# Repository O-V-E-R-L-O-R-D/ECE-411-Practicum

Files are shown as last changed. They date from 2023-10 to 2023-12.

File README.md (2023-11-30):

# ECE-411-Practicum Project

## Color Sensor State Diagram


## Bootload and Programming
**Library for Bootload Raw Chip:** https://github.com/MCUdude/
MiniCore

**1.) Add "https://mcudude.github.io/MiniCore/package_MCUdude_MiniCore_index.json" to Arduino IDE's "Additional boards manager URL's"**

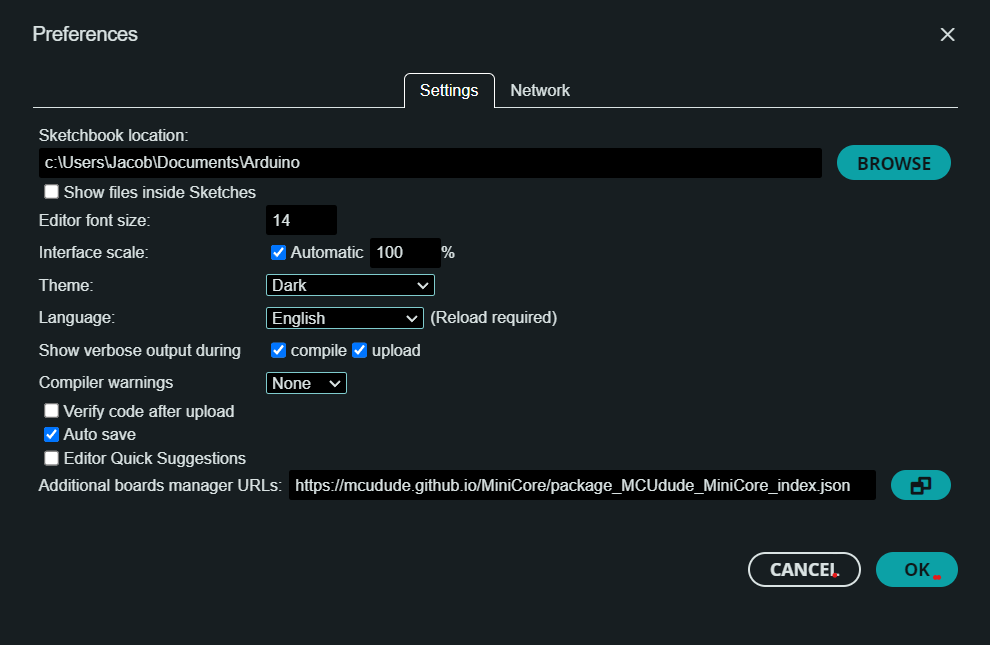
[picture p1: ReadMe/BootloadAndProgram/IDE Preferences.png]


---
**2.) Open example project "AruinoISP"**

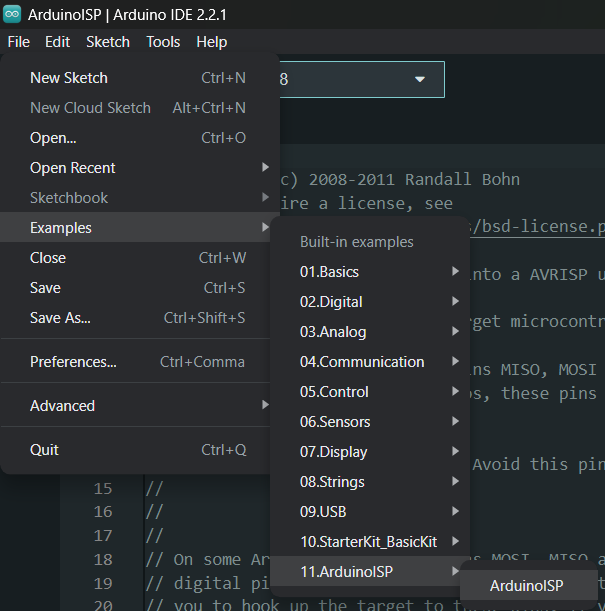
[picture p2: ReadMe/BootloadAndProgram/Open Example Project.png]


---
**3.) Program Arduino Uno for programming by clicking "Upload button" with the Aruino Uno board selected. Also in the "Tools" tab select "ArduinoISP" for programmer** 

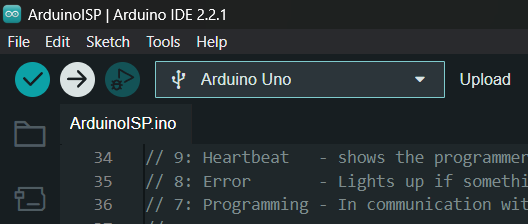
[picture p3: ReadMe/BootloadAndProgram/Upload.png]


---
**4.) Make connections from Aruduino Uno to PCB. On PCB, move bottem left switch to Program Mode (PRGM) by sliding the switch to the left**

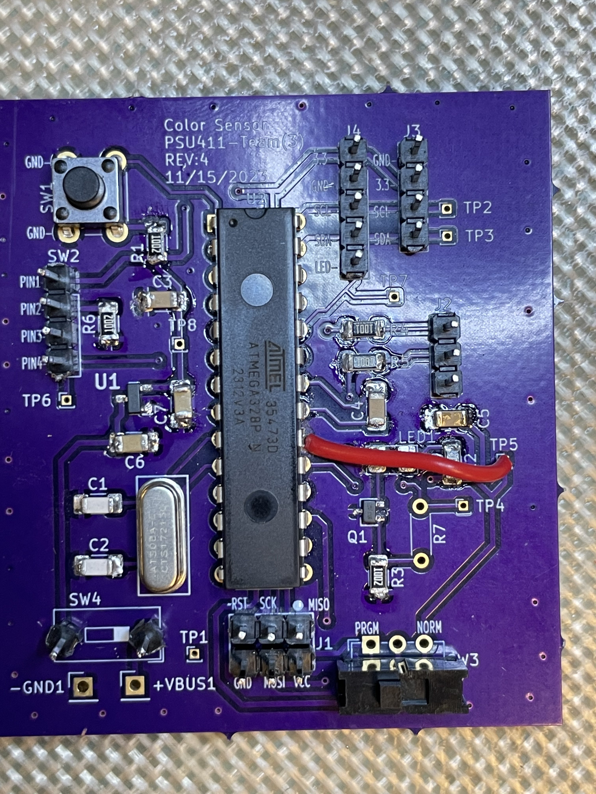
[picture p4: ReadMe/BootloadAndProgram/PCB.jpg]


| Arduino Uno |->| PCB |
|---|--|-----|
|5V |->|VCC  | 
|GND |->|GND  |
|13 |->|CLK  |
|12 |->|MISO |
|11 |->|MOSI |
|10 |->|Reset|

---
**5.) Bootload ATmega328 by opening "Tools tab and clicking "Burn Bootloader" after changing the settings to the ones seen below.**  
Board: "ATmega328"
BOD: 2.7V  
Clock: "External 8MHz"  
EEPROM: "EEPROM not retained"  (Not Necessary, For Clearing Color Calibration data)  
Variant: "328P/32PA"  
Programmer: "Arduino as ISP"  

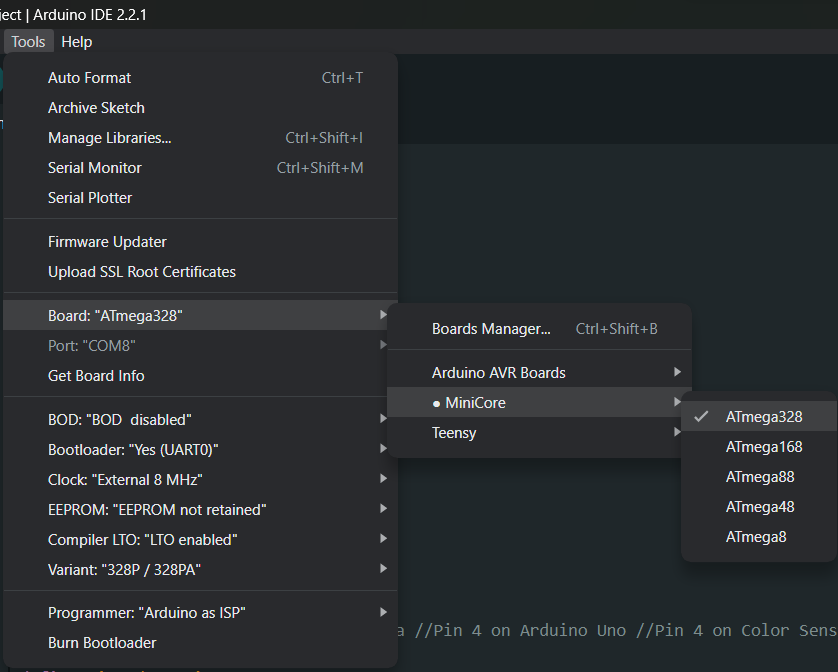
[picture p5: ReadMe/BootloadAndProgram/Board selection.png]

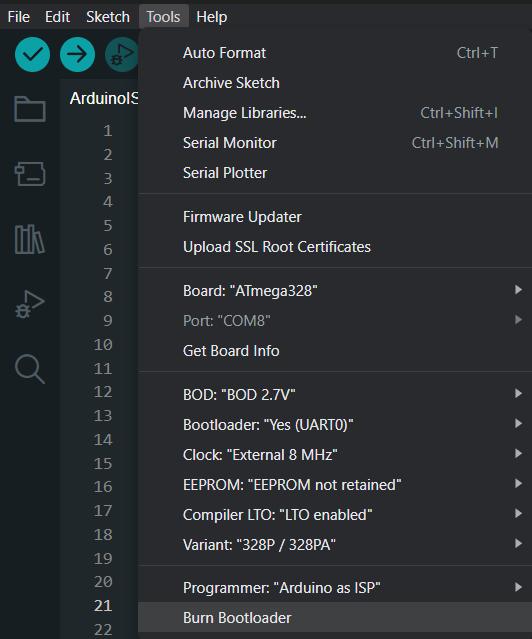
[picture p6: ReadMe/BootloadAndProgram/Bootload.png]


---
**6.) Switch to RGB_Sensor_Project.ino ("ECE-411-Practicum/RGB_sensor_project/RGB_sensor_project.ino"). Open Tools tab and make sure "Programmer" is set to "Arduino as ISP".With the ATmega328 board selected, open the "Sketch" tab and click "Upload Using Programmer"**

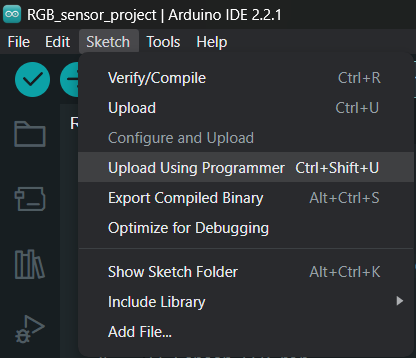
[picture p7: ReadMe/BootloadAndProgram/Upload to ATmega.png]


---
**7.) Unplug Programming connectings to PCB and flip the bottom right switch on the PCB to "NORM" mode. Make sure the PCB is getting power from the batter to the PCB. If this is the firt time programming the device the OLED should show that it's entering calibration mode.**  

**NOTE:** After first bootload you don't need to do it again for that chip. If you want to upload a new Schetch to the chip you only need to flip bottem left switch to PRGM, make the right programming connections, and then go straight to step 6.

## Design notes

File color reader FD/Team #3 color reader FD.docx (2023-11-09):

Team #3

Functional Decomposition

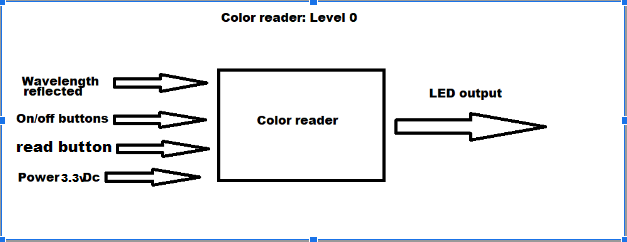
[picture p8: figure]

Module | Color reader
Inputs | Color: wavelength On/Off and read control: buttons Power: 3.3v Dc
Outputs | Led displaying the color
Functionality | Reads the reflected wavelength then converts and displays the color on the LCD. User should be able to turn it on/off and when to take the a new reading

Color reader: Level 1

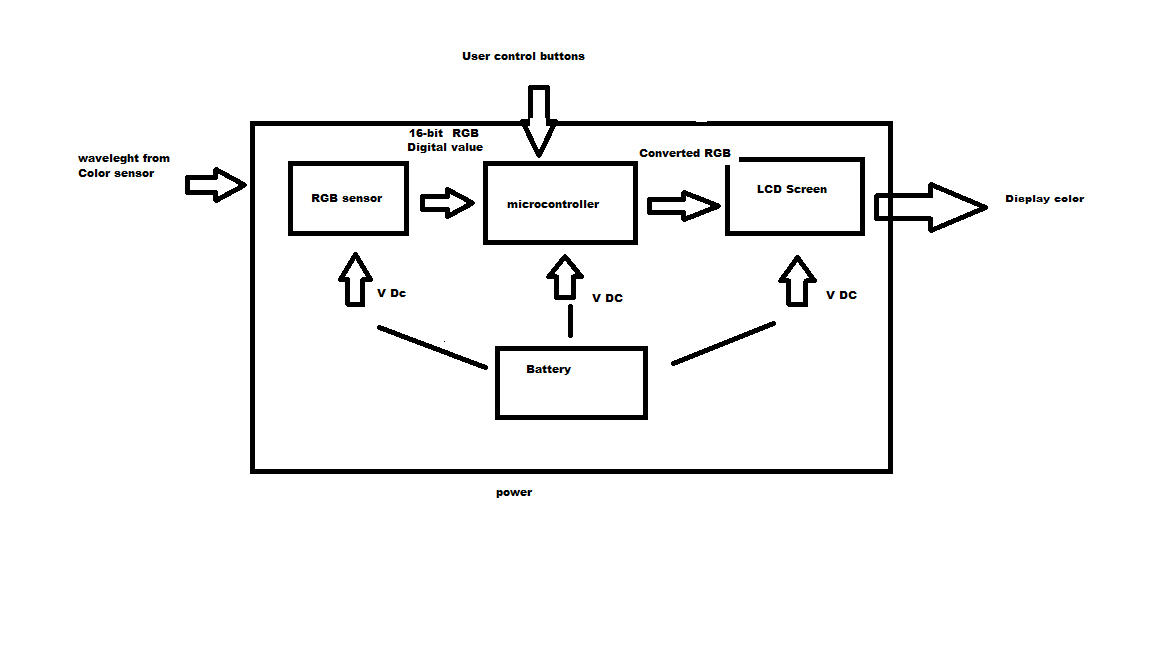
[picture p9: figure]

Module | RGB sensor
Inputs | Wavelength reflected Power: 0.5v to 3.8v
Outputs | RGB 16-bit Digital value
Functionality | Provides a digital value of RGB of incoming light

Module | Battery
Inputs | Power 9V
Outputs | 9V dc battery
Functionality | Provide power to turn on

Module | LCD screen
Inputs | Converted RGB digital Power: 5v
Outputs | Readable information
Functionality | Displays to the user the color

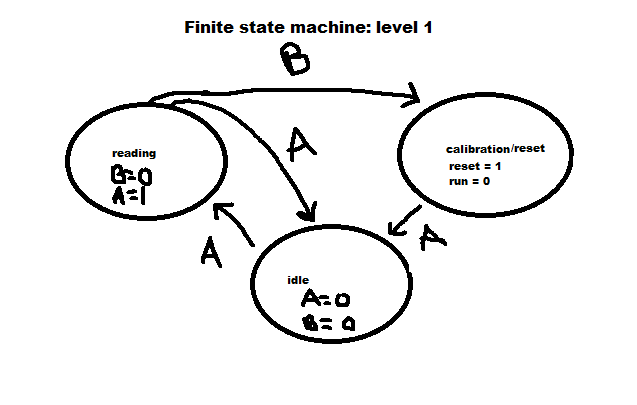
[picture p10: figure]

Module | microcontroller
Inputs | Power: 2.7v to 5.5v Clock: 0 to 8MHz Color sensor
Outputs | Reset/read modes LCD Color sensor
Functionality | Changes the color sensor from reset and run modes

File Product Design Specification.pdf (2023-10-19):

# HW Wk 04 - Product Design Specification ECE 411

# Team #3:

## Jacob Louie (jlouie@pdx.edu) Vladimir Grigoriev (vg8@pdx.edu) Kiryl Rabushka (rabushka@pdx.edu) Tristan Josue (jtristan@pdx.edu)

## Instructor: Andrew Greenberg

## ECE DEPARTMENT

PORTLAND STATE UNIVERSITY

Product summary:
Our product is a pen shaped color picker. By pointing the tip of the pen at an object, it can display the hex color code of that object. This hex code can then be replicated into your own digital art project by using that same hex code. This device can be especially helpful for people that are color-blind. Outside digital projects, it can also be used to match the paint color of an object in order to apply some new paint. This product is for anyone that might need some help restoring or bringing to life the colors of reality for your projects.

“Market” Analysis:
Targeted Customers: Digital artist, painters, interior designers, DIY projects, and color-blind people.

Competition: Other color analysis software/app, cheaper color readers, “eyeball test”

Price: 50$ this is our reference price based on the research of similar projects.

We may have to lower the price in the future baced on the components we use to make it much cheaper for the customers. Other color analysis devises on the internet are much more complex and cost a lot of money. We shoot for cheap smal device for everyday life and easy to use, so everyone can easily have hands on it and do not spent a lot of money.

Requirements:
- Must: Read color, output a hex code to display, be portable, run on battery.
- Should: Be small and light, have an LED or a buzzer to indicate the state of color identification process.
- May: Give out the complementary colors, ergonomic, rechargeable, have an app, have an RGB LED to display the color

System Architecture:
Those are the major parts we will be using in our product:
- Color Sensor
- Microcontroller
- Battery
- Voltage regulator
- Display

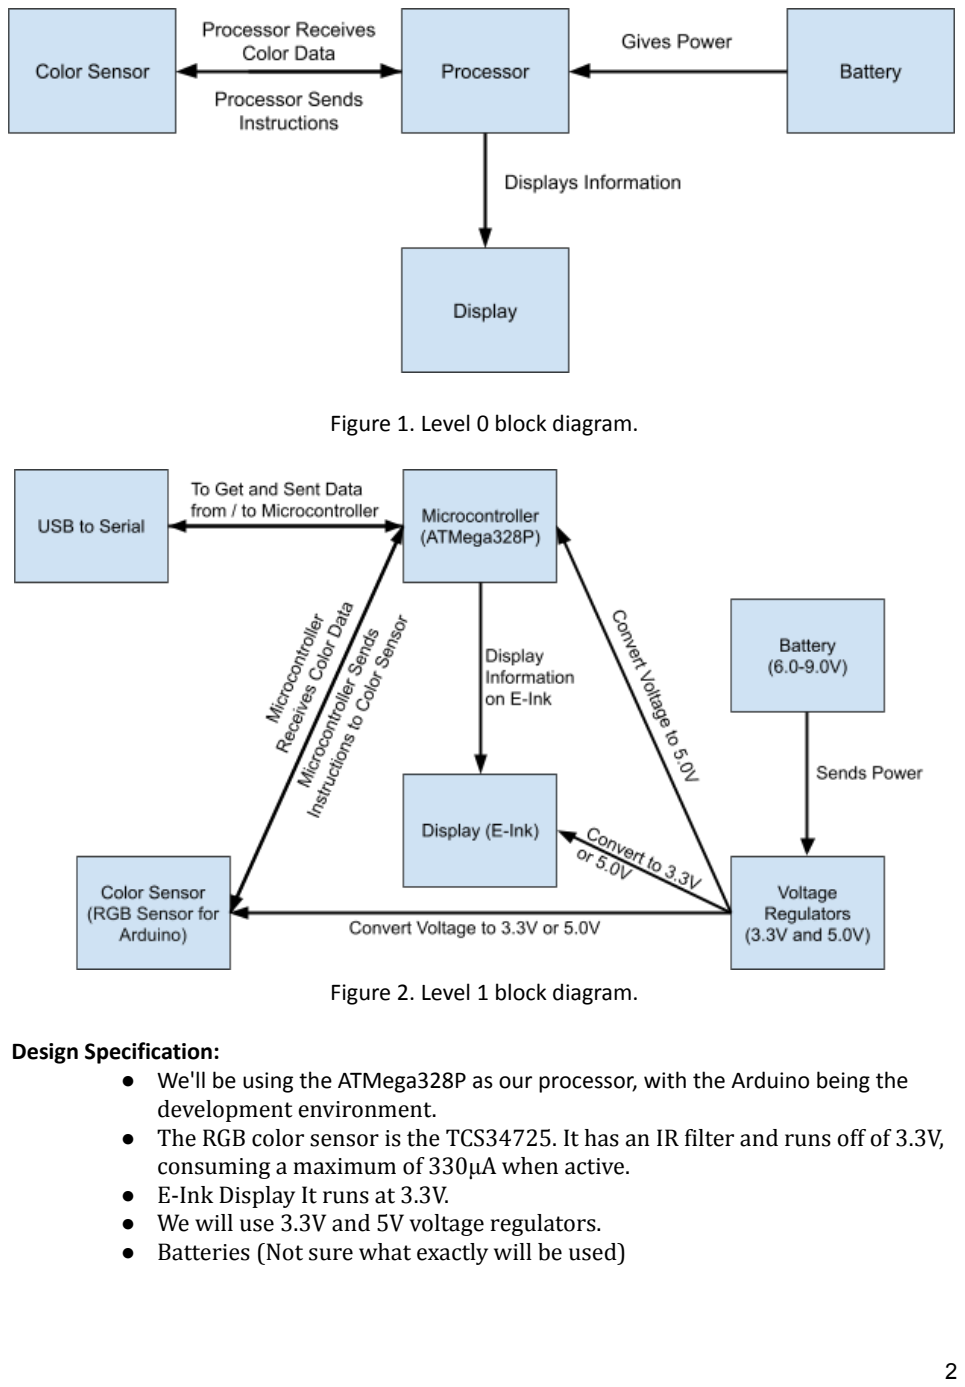
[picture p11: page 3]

Figure 1. Level 0 block diagram.

Figure 2. Level 1 block diagram.

Design Specification:
- We'll be using the ATMega328P as our processor, with the Arduino being the development environment.
- The RGB color sensor is the TCS34725. It has an IR filter and runs off of 3.3V, consuming a maximum of 330μA when active.
- E-Ink Display It runs at 3.3V.
- We will use 3.3V and 5V voltage regulators.
- Batteries (Not sure what exactly will be used)

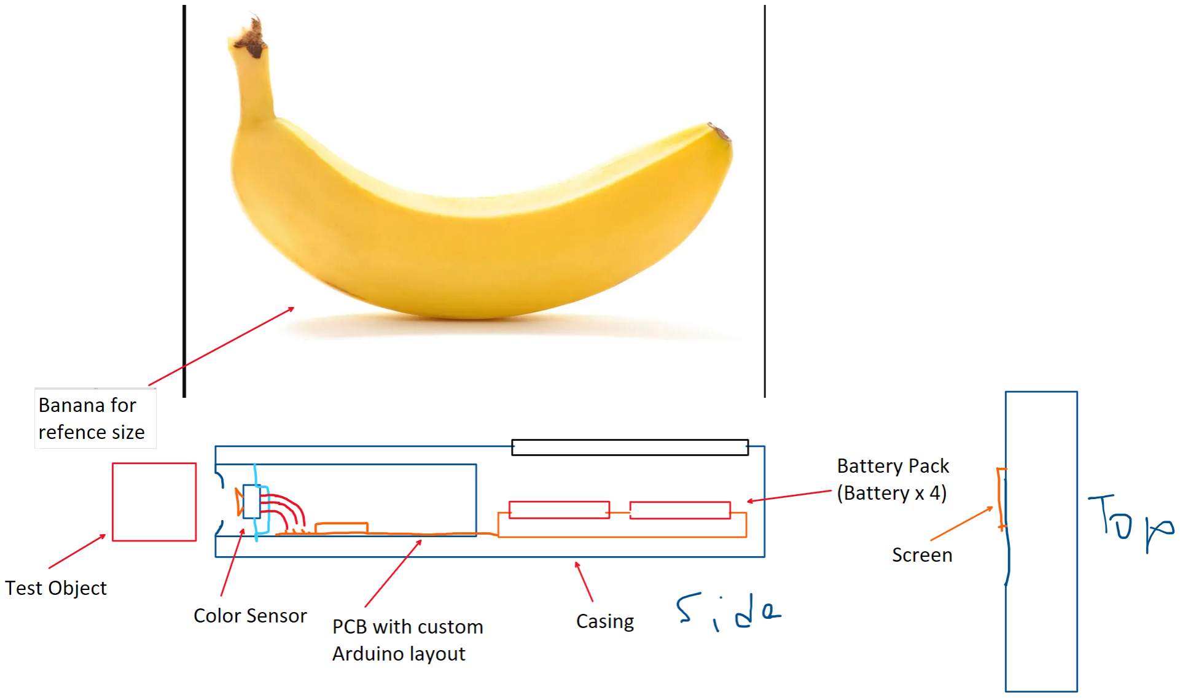
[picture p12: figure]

Figure 3.Example of our product.

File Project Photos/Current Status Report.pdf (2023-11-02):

# Current Status Report ECE 411

# Team #3:

## Jacob Louie (jlouie@pdx.edu) Vladimir Grigoriev (vg8@pdx.edu) Kiryl Rabushka (rabushka@pdx.edu) Tristan Josue (jtristan@pdx.edu)

## Instructor: Andrew Greenberg

ECE DEPARTMENT
PORTLAND STATE UNIVERSITY

The current state of the breadboard prototype:
- Works on Arduino Uno board
- Display works and shows hex value for the color sensed
- Color sensor works and can detect colors
- We have basics for calibrating to black and white colors for reference to get better readings
- We added a button that switches modes allowing the circuit to idle when not taking readings
What can be improved:
- Get an understanding of how to calibrate the device better
- Work with the mode states to make the color sensor more power-efficient
What should be done:
- Build our own “Arduino board” using ATMEGA chip
- Make an isolated place from the surroundings for the sensor to get readings (3d print case)

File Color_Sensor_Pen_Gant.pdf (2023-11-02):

23 | 29
5 | 12 | 19 | 26

3

Oct '23 | Nov '23 | Dec '23
Color Sensor Pen | 0h | 1%
Version 1 | 0h | 1%
Schematic & PCB Design | 0h | 0%
General PCB layout
0 | 0%
KICAD PCB
0 | 0%
Schematic with actual values we're...
0 | 0%
Power Consumption Testing
0 | 0%
PCB final layout
0 | 0%
Prototype Color Sensor on bread... | 0h | 3%
Hook up RGB color sensor
0 100%
Calibrate RGB color sensors
0 | 0%
Test accuracy of sensor
0 | 0%
Physical Enclosure | 0h | 0%
Brainstorm design | 0h | 0%
Draw on paper
0 | 0%
3D designing on CAD | 0h | 0%
Draft designing using Onshape
0 | 0%
Share and print
0 | 0%
Test for fitting
0 | 0%
Final designing
0 | 0%
Code | 0h | 0%
High level code | 0h | 0%
Functions
0 | 0%
flow chart
0 | 0%
Functions code | 0h | 0%
Color convert to hex | 0h | 0%
Debugging Color convert to hex
0 | 0%
Output to LCD screen | 0h | 0%
Debugging Output to LCD scre...
0 | 0%
Button on/off | 0h | 0%
Debugging Button on/off
0 | 0%

Powered by TCPDF (www.tcpdf.org)

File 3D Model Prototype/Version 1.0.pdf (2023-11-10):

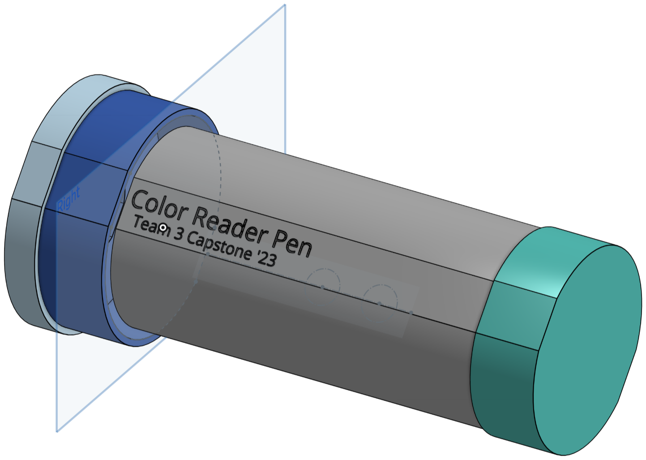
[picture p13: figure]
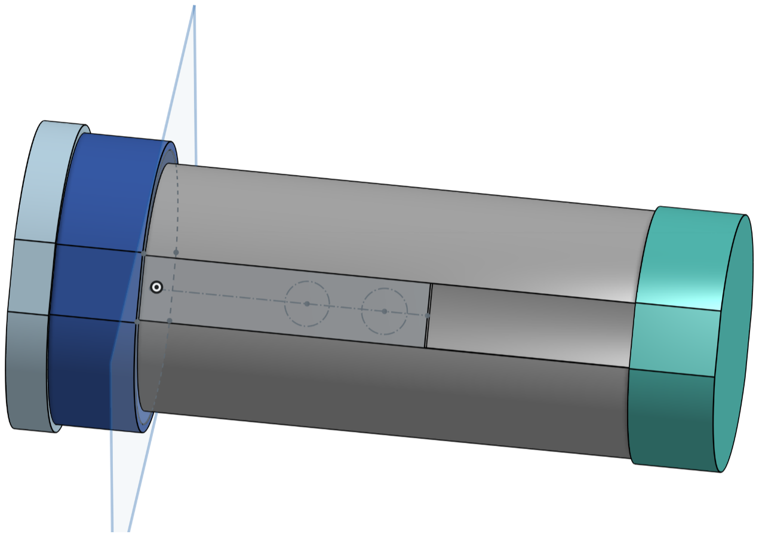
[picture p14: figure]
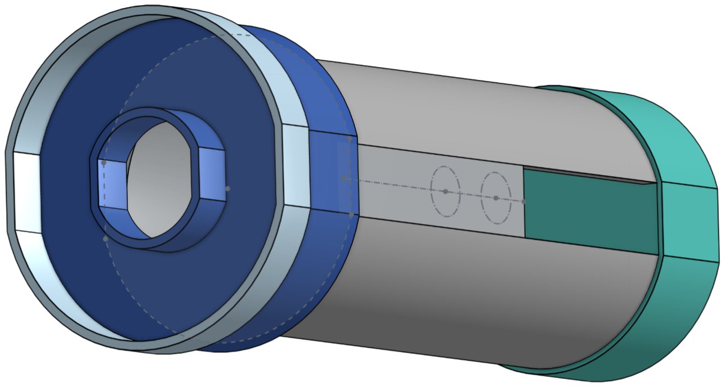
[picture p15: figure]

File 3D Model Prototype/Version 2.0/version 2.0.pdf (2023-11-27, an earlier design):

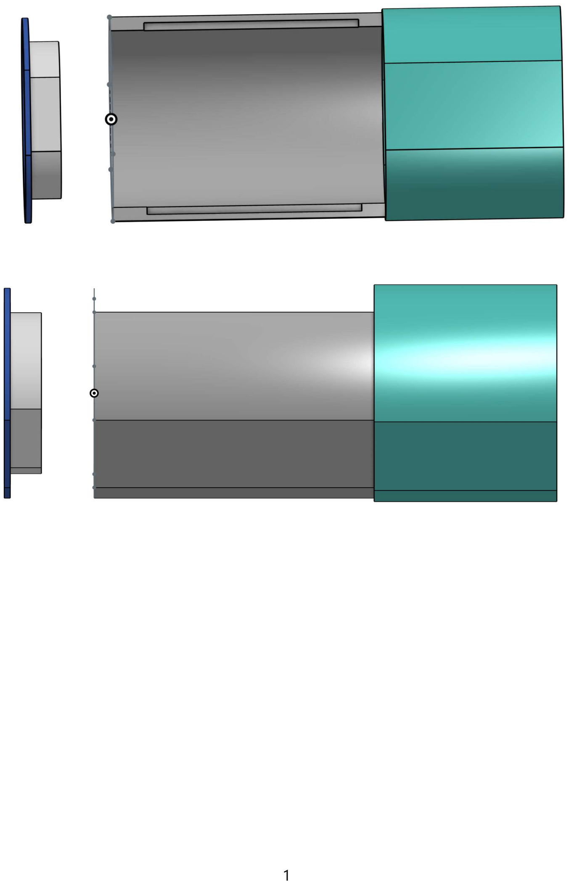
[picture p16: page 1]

1

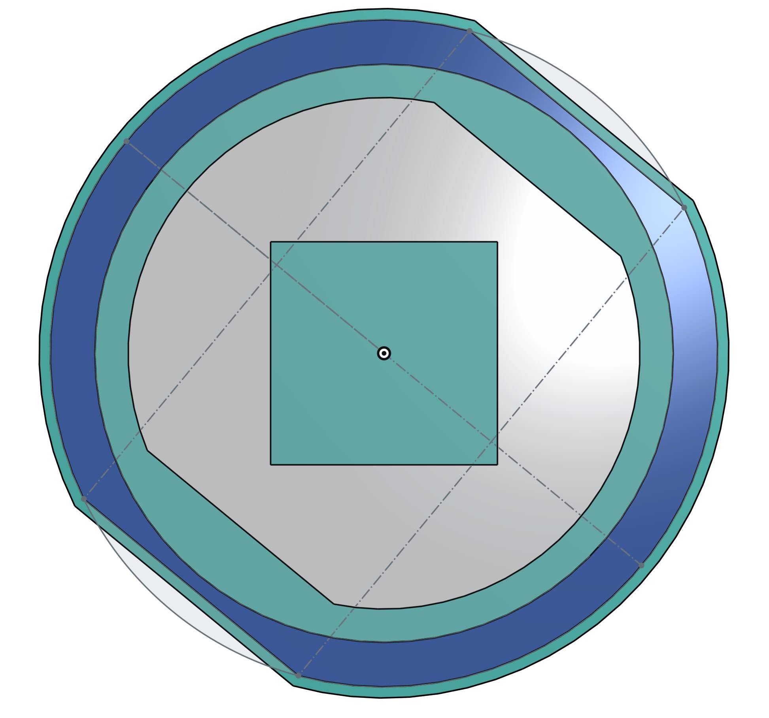
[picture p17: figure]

2

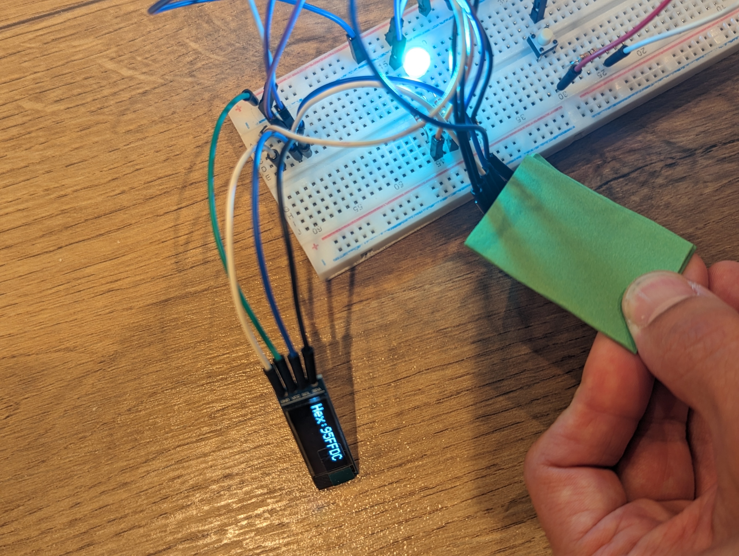
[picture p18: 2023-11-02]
Project Photos/Prototype_Green_Color.jpg

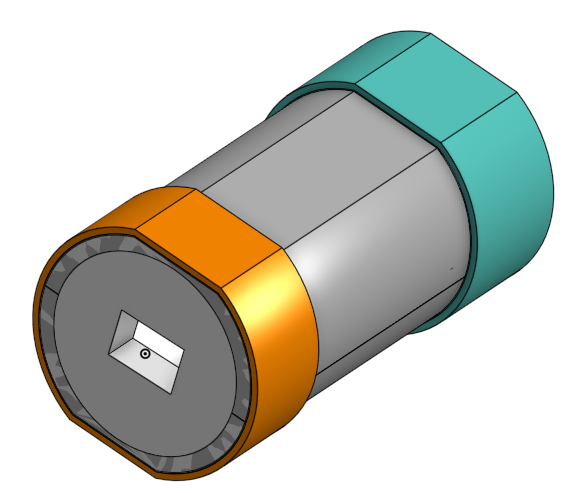
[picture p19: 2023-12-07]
3D Model Prototype/Version 4.0/action2.png

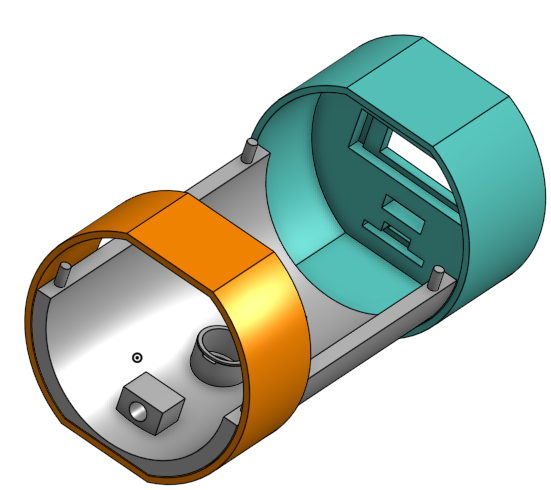
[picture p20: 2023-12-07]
3D Model Prototype/Version 4.0/action3.png

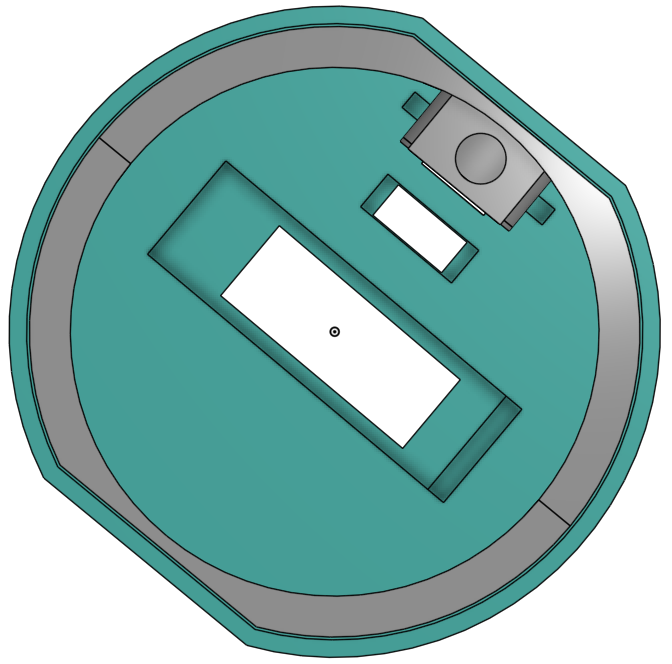
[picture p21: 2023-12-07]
3D Model Prototype/Version 4.0/front.png

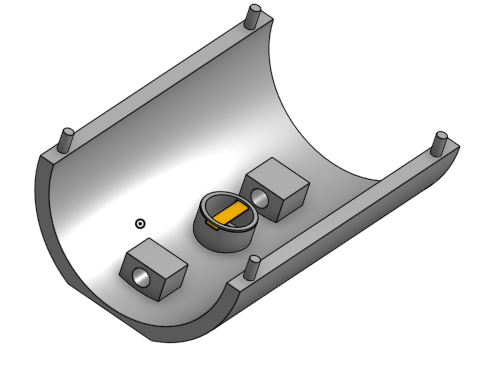
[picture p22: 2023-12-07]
3D Model Prototype/Version 4.0/action4.png

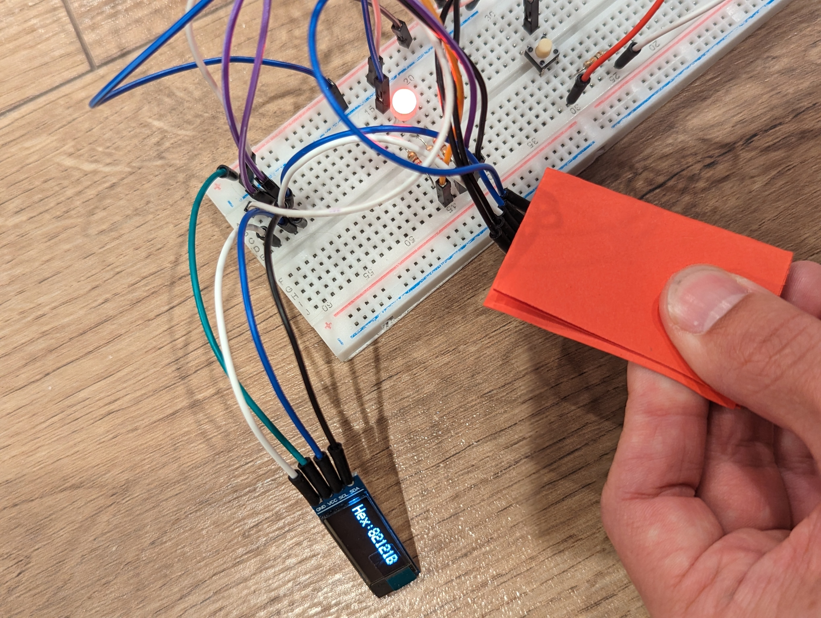
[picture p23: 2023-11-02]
Project Photos/Prototype_Red_Color.jpg

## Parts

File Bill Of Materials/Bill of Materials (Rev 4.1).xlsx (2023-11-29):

Bill of Materials for: TEAM 3, Color Sensor Pen
Last Modified 11/10/2023
PCB Rev: 4.0
BOM Version: 4.0 |  | P/NP = Place/ Not Place (on PCB board)
Count | Part Refernce | P/NP | Mfg | Mfg Part # | Description | Dist | Dist Part Number | Unit Price (Q=1) | Cost Total (Per Device)
2 | C1, C2 | P | KEMET | C1206C430J5GAC7800 | 43 pF ±5% 50V Ceramic Capacitor C0G, NP0 1206 (3216 Metric) | Digikey | 399-14687-1-ND | $0.39 | $0.78
2 | C4, C5 | P | Samsung Electro-Mechanics | CL31B104KBCNFNC | 0.1 µF ±10% 50V Ceramic Capacitor X7R 1206 (3216 Metric) | Digikey | 1276-2744-1-ND | $0.11 | $0.22
2 | C6, C7 | P | Samsung Electro-Mechanics | CL31B105KAHNFNE | 1 µF ±10% 25V Ceramic Capacitor X7R 1206 (3216 Metric) | Digikey | 1276-3086-1-ND | $0.13 | $0.26
1 | D1 | P | Lite-On Inc. | LTST-T680TBWT | Blue 470nm LED Indication - Discrete 3.3V 2-LCC (J-Lead) | Digikey | 160-2182-1-ND | $0.41 | $0.41
1 | J1 | P | Adam Tech | PH2-06-UA | Connector Header Through Hole 6 position 0.100" (2.54mm) | Digikey | 2057-PH2-06-UA-ND | $0.13 | $0.13
1 | J2 | P | Oupiin | 68001-400HLF | 1X3 Connector Header Through Hole 8 position 0.100" (2.54mm) | Digikey | 2553-2011-1X08TSB-ND | $0.08 | $0.08
1 | J3 | P | Oupiin | 68001-400HLF | 1X4 Connector Header Through Hole 8 position 0.100" (2.54mm) | Digikey | 2553-2011-1X08TSB-ND | $0.08 | $0.08 | Note: only need to buy 1 for both J3 and J4
1 | J4 | P | Oupiin | 68001-400HLF | 1X5 Connector Header Through Hole 8 position 0.100" (2.54mm) | Digikey | 2553-2011-1X08TSB-ND | $0.08
1 | U1 | P | Diodes Incorporated | AP2120N-3.3TRG1 | LDO Voltage Regulators 250mA CMOS LDO 3.3V 200mV | Mouser | 621-AP2120N-3.3TRG1 | $0.38 | $0.38
1 | U1 (Alternative) | NP | Richtek | RT9078-33GJ5 | LDO Voltage Regulators 2uA IQ, 300mA Low-Dropout Linear Regulator | Mouser | 835-RT9078-33GJ5 | $0.36
1 | Q1 | P | Diodes Incorporated | DMN63D8LW-13 | N-Channel 30 V 380mA (Ta) 300mW (Ta) Surface Mount SOT-323 | Digikey | DMN63D8LW-13DICT-ND | $0.24 | $0.24
3 | R1, R3, R6 | P | Stackpole Electronics Inc | RMCF1206FT10K0 | 10 kOhms ±1% 0.25W, 1/4W Chip Resistor 1206 (3216 Metric) Automotive AEC-Q200 Thick Film | Digikey | RMCF1206FT10K0CT-ND | $0.10 | $0.30
3 | R2, R4, R5 | P | Stackpole Electronics Inc | RMCF1206FT1K00 | 1 kOhms ±1% 0.25W, 1/4W Chip Resistor 1206 (3216 Metric) Automotive AEC-Q200 Thick Film | Digikey | RMCF1206FT1K00CT-ND | $0.10 | $0.30
1 | SW1 | P | CUI Devices | TS02-66-60-BK-100-SCR-D | Tactile Switch SPST-NO Top Actuated Through Hole | Digikey | 2223-TS02-66-60-BK-100-SCR-D-ND | $0.10 | $0.10
1 | SW2 | NP | C&K | D6R90 F1 LFS | Pushbutton Switch SPST-NO Keyswitch Through Hole | Digikey | 401-1978-ND | $1.30 | $1.30
1 | SW3 | P | C&K | JS202011CQN | Slide Switch DPDT Through Hole | Digikey | 401-2001-ND | $0.67 | $0.67
1 | SW4 | NP | C&K | JS202011CQN | Slide Switch DPDT Through Hole | Digikey | 401-2001-ND | $0.67 | $0.67
4 | TP1-T8 | NP | NA | NA | TestPoint | NA |  | $0.00 | $0.00
1 | U2 | P | Microchip Technology | ATMEGA328P-PN | 8-bit Microcontrollers - MCU AVR 32K FLSH 2K SRAM 1KB EE-20 MHZ 105C | Mouser | 556-ATMEGA328P-PN | $3.03 | $3.03
1 | U2 (Alternative) | NP | Microchip Technology | ATMEGA328PB-AN | 8-bit Microcontrollers - MCU ATMEGA328PB 20MHZ Extd. Temp | Mouser | 556-ATMEGA328PB-AN | $1.74
1 | Y1 | P | CTS-Frequency Controls | ATS08A-E | 8 MHz ±30ppm Crystal 20pF 60 Ohms HC-49/US | Digikey | CTX1054-ND | $0.26 | $0.26
1 |  | NP | NA | NA | I2C Display Module 0.91 Inch Resolution: 128 x 32 3.3V~5V | Amazon | B08L7QW7SR | $2.79 | $2.79
1 |  | NP | TinyCircuits | ASR00050 | 18650 3.7 V Lithium-Ion Battery Rechargeable (Secondary) 2.5Ah | Digikey | 1832-1050-ND | $6.95 | $6.95
1 |  | NP | ‎AITRIP | ‎EC16986 | TCS34725 RGB Light Color Sensor | Amazon | B08L7MS8L4 | $3.66 | $3.66
1 |  | NP | HiLetgo | ‎3-01-0205 | HiLetgo 10pcs 5V 1A 18650 Lithium Battery Charging Board TP4056 | Amazon | B00LTQU2RK | $0.78 | $0.78
1 |  | NP | NA | NA | Battery Storage Box Case Holder for 18650 | Amazon | B07KD9JLH3 | $0.84 | $0.84
 |  |  |  |  |  |  |  | Total = | $24.22

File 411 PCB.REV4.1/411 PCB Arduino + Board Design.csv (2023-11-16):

Source: | C:\Users\kiryl\OneDrive\School One Drive\ECE 2023\ECE 411 Industry Design Process\Github ECE 411\ECE-411-Practicum\411 PCB.REV4\411 PCB Arduino + Board Design.kicad_sch
Date: | 11/15/2023 10:25:21 PM
Tool: | Eeschema 7.0.8
Generator: | G:\Programs\KiCad\7.0\bin\scripting\plugins/bom_csv_grouped_by_value.py
Component Count: | 37
Collated Components:
Item | Qty | Reference(s) | Value | LibPart | Footprint | Datasheet | DNP | Arrow Part Number | Arrow Price/Stock | Height | Manufacturer_Name | Manufacturer_Part_Number | Mouser Part Number | Mouser Price/Stock
1 | 2 | +VBUS1, -GND1 | Conn_01x01_Pin | Connector:Conn_01x01_Pin | Connector_PinHeader_2.54mm:PinHeader_1x01_P2.54mm_Vertical | ~
2 | 2 | C1, C2 | 43p | Device:C | Capacitor_SMD:C_1206_3216Metric_Pad1.33x1.80mm_HandSolder | ~
3 | 3 | C3, C4, C5 | 100n | Device:C | Capacitor_SMD:C_1206_3216Metric_Pad1.33x1.80mm_HandSolder | ~
4 | 2 | C6, C7 | 1uF | Device:C | Capacitor_SMD:C_1206_3216Metric_Pad1.33x1.80mm_HandSolder | ~
5 | 1 | J1 | ICSP CONN | :Conn_PIC_ICSP_ICD_1 | PH2_06_UA:CONN_PH2-06-UA_ADM | http://ww1.microchip.com/downloads/en/devicedoc/30277d.pdf
6 | 1 | J2 | ~ | Connector_Generic:Conn_01x03 | Connector_PinHeader_2.54mm:PinHeader_1x03_P2.54mm_Vertical
7 | 1 | J3 | Conn_01x04 | Connector_Generic:Conn_01x04 | Connector_PinHeader_2.54mm:PinHeader_1x04_P2.54mm_Vertical
8 | 1 | J4 | Conn_01x05_Pin | Connector:Conn_01x05_Pin | Connector_PinHeader_2.54mm:PinHeader_1x05_P2.54mm_Vertical | ~
9 | 1 | LED1 | Blue LED (100mA Max) | Device:LED | LED_SMD:LTST-B680 | ~
10 | 1 | Q1 | Q_NMOS_GDS | 2023-11-13_01-53-07:DMN63D8LW-13 | DMN63D9LW:SOIC_D8LW-13_DIO | DMN63D8LW-13
11 | 3 | R1, R3, R6 | 10k | Device:R | Resistor_SMD:R_1206_3216Metric | ~
12 | 3 | R2, R4, R5 | 1k | Device:R | Resistor_SMD:R_1206_3216Metric | ~
13 | 1 | R7 | 0 Ohm | Device:R | Resistor_THT:R_Axial_DIN0204_L3.6mm_D1.6mm_P5.08mm_Horizontal | ~
14 | 1 | SW1 | SW_SPST | Switch:SW_SPST | Button_Switch_THT:SW_PUSH_6mm | ~
15 | 1 | SW2 | SW_MEC_5E | Switch:SW_MEC_5E | Connector_PinHeader_2.54mm:PinHeader_1x04_P2.54mm_Vertical | http://www.apem.com/int/index.php?controller=attachment&id_attachment=1371
16 | 1 | SW3 | SW_SPDT | Switch:SW_DPDT_x2 | Button_Switch_THT:SW_E-Switch_EG1271_SPDT_123 | ~
17 | 1 | SW4 | SW_DPST_x2 | Switch:SW_DPST_x2 | Button_Switch_THT:SW_DIP_SPSTx01_Slide_9.78x4.72mm_W7.62mm_P2.54mm | ~
18 | 8 | TP1, TP2, TP3, TP4, TP5, TP6, TP7, TP8 | TestPoint | Connector:TestPoint | Connector_PinHeader_1.00mm:PinHeader_1x01_P1.00mm_Vertical | ~
19 | 1 | U1 | ~ | SamacSys_Parts:AP2120N-3.3TRG1 | SamacSys_Parts:SOT96P240X120-3N | https://componentsearchengine.com/Datasheets/1/AP2120N-3.3TRG1.pdf |  | AP2120N-3.3TRG1 | https://www.arrow.com/en/products/ap2120n-3.3trg1/diodes-incorporated?region=nac | 1.2 | Diodes Inc. | AP2120N-3.3TRG1 | 621-AP2120N-3.3TRG1 | https://www.mouser.co.uk/ProductDetail/Diodes-Incorporated/AP2120N-3.3TRG1?qs=x6A8l6qLYDA1usfeaZ7Tnw%3D%3D
20 | 1 | U2 | ATmega328P-P | MCU_Microchip_ATmega:ATmega328P-P | Package_DIP:DIP-28_W7.62mm | http://ww1.microchip.com/downloads/en/DeviceDoc/ATmega328_P%20AVR%20MCU%20with%20picoPower%20Technology%20Data%20Sheet%2040001984A.pdf
21 | 1 | Y1 | 8 MHz | Device:Crystal | footprints:ATS08A-E_CTS | ~

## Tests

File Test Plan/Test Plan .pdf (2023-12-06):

# HW Wk 10 - Test Plan ECE 411

# Team #3:

## Jacob Louie (jlouie@pdx.edu) Vladimir Grigoriev (vg8@pdx.edu) Kiryl Rabushka (rabushka@pdx.edu) Tristan Josue (jtristan@pdx.edu)

## Instructor: Andrew Greenberg

ECE DEPARTMENT
PORTLAND STATE UNIVERSITY
2023-12-03 | Page 1 of 9

Test Author: Kiryl Rabushka
Test Case Name: | Initial turn on | Test ID #: | 0001
Description: | This is a first initial turn on test to check if the power supply with a bare chip works. Here, we will test all voltage rails and voltage pins before loading data onto the chip. We will then switch to the programming state and flip the programming switch to see if our switch logic works. | Type: | ✓ white box □ black box □ ________

Tester Information
| Name of Tester: | Kiryl Rabushka | Date: | 10/27/2023
| HW/SW Version: | HW: Rev 4, SW: None | Time: | 13:30
| Setup: | Here we have an assembled board connected to the power supply at very low current. We also have a multimeter that we will use to probe the test points and voltage rails on the board before and after the LDO. We will also test if our rails reach where they need to. Ex. LCD, ATMEGA. The power supply was set to 3.3V and then tested again at 4.0V. Once that is done, we will connect an Arduino and use its pins to check if our logic with the programming switch works and does not connect 5V to other pins.
S T E P | Action | Expected Result | P A S S | F A I L | N / A | Comments
1 | Probe the input of LDO | 3.3V input | ✓
2 | Probe the output of LDO | 3.3V output | ✓ | | | Output shows 3.3V
3 | Probe the input to the ATMEGA | 3.3V | ✓
4 | Connect the Arduino programming setup and test voltage rails | See no voltage on 3.3V rails. Only see 5V on the VCC of the chip. | | ✕ | | I saw about 4.3~4.6V on 3.3V voltage rails. That means something was sending voltage to the 3.3V LDO output line. I figured that the VCC was also connected internally to AVCC and AREF. Cut the leg of AVCC from ATMEGA because it had an internal connection to VCC
5 | Repeat actions from STEP 4 | No voltage below 3.3V on the LDO line | ✓ | | | The voltage on the LDO line was still present, but was greatly lower. It went from 4.5V to 2.7V
| Overall test result: At this point, it is fine that LDO has 2.7V because it is below the threshold to break any component on a 3.3V line. Overall, the board worked as expected with minor changes. | | ✓ | | | We later found that VCC was also holding the reset line high because it was an (active) low pin. The reset line has a 3.3V connection to it through a 10k resistor.

Example Test Case

Test Author: Kiryl Rabushka
Test Case Name: | Final Test before case assembly | Test ID #: | 0002
Description: | This test is the final test before putting all the boards and wiring into the case. At this point, the board has soldered connections and does not use anything from the breadboard. We will test the functionality of all systems at this point. The board has the latest SW version 1.1. | Type: | □ white box ✓ black box □ ________

Tester Information
| Name of Tester: | Kiryl Rabushka | Date: | 10/30/2023
| HW/SW Version: | HW: Rev 4, SW: Final Version 2.0 | Time: | 23:30
| Setup: | Multimeter, Battery attached to the PCB with LCD screen and Color Sensor
S T E P | Action | Expected Result | P A S S | F A I L | N / A | Comments
1 | Plug the battery into the slot battery slot | 3.7V on the PCB +VCC before enable the switch | ✓ | | | 3.3V before closed switch
2 | Close the switch and measure the voltage on the input of LDO | 3.7V on the LDO input | | ✕ | | Saw about 0.3V on the LDO input. After some tinkering, the LDO blew up and released smoke. Had to cut the GND wire to stop further damage. I later found that during the final assembly, I put +3.3V LDO output attached to the SDA pin on the LCD board. I replaced the pins how they should be.
3 | Repeat STEP 2 | 3.7V on the LDO input | ✓
4 | Test voltages and observe the LCD and color sensor behaviors | 3.3V on the output LCD turns on and displays a smiley face Color sensor LED off during idle phase | ✓
5 | Put a color paper in front of the color sensor and press the button to ask for the color sensing state | Color sensor LED turns on Display the HEX color data on the LCD | ✓ | | | Verified the HEX data values with an online translator, and it showed the correct color values
| Overall test result: Pre-assembly worked and is ready to be put into the case | | ✓

Test Author: Jacob Louie
Test Case Name: | The basic functionality of the color sensor | Test ID #: | 0003
Description: | Testing the basic functionality of the color sensor isolated from the rest of the modules. Verify that it is seeing the correct values after calibration and that it works at 3.3V. | Type: | □ white box ✓ black box □ ________

Tester Information
| Name of Tester: | Jacob Louie | Date: | 12/28/2023
| HW/SW Version: | HW: Rev 4, SW: First Version 1.0 | Time: | 5:30PM
| Setup: | Hook up display to Arduino Uno with I2C at 3.3V and 5V. Add calibration to the simple example project for the color sensor and see the output on the serial line.
Test Action | | Expected Result | Pass | Fail | N/A | Comments
1 | Show RED | #FF0000 | ✅ | | | Wasn’t exactly the expected values, but was almost the same visually when you looked up the hex color code.
2 | Show Blue | #0000FF | ✅ | | | Wasn’t exactly the expected values, but was almost the same visually when you looked up the hex color code.
3 | Show Green | #00FF00 | ✅ | | | Wasn’t exactly the expected values, but was almost the same visually when you looked up the hex color code.
4 | Show White | #FFFFFF | ✅ | | | It is the exact same as expected because it’s calibrated off of this color.
5 | Show Black | #00000 | ✅ | | | It is the exact same as expected because it’s calibrated off of this color.
6 | Works the same at 3.3V as it does at 5V | Run the same test as above on both 3.3V and 5V, and we should get the same results. | ✅ | | | Works the same on both voltages.
| Overall test result: | | ✅ | | | Getting good color results.

Test Author: Jacob Louie
Test Case Name: | The basic functionality of the OLED Display | Test ID #: | 0004
Description: | Testing the basic functionality of the Display isolated from the rest of the modules. Verify that it is outputting text and works at 3.3V. | Type: | □ white box ✓ black box □ ________

Tester Information
| Name of Tester: | Jacob Louie | Date: | 10/28/2023
| HW/SW Version: | HW: Rev 4, SW: First Version 1.0 | Time: | 6:30PM
| Setup: | Hook up display to Arduino Uno with I2C at 3.3V and 5V.
Test Action | | Expected Result | Pass | Fail | N/A | Comments
1 | Display example project | See images for example project on display | ✅ | | | Works how it should
2 | Display text and number | See the test and numbers on the display | ✅ | | | Works how it should
3 | Refresh display with new text | See text 1 and then text 1 goes away and then text 2 is displayed | ✅ | | | Works how it should
4 | Works the same at 3.3V as it does at 5V | Run the same test as above on both 3.3V and 5V, and we should get the same results. | ✅
| Overall test result: | | ✅ | | | Does what’s expected.

Test Author: Jacob Louie
Test Case Name: | Test calibration state in code | Test ID #: | 0005
Description: | Make sure the calibration is saving the values after the chip loses power. Verify that the chip will enter calibration mode when first programmed. Verify that the chip will enter calibration mode when holding down the color collection button. Verify that it will go to idle mode after calibration is complete. | Type: | ✓ white box □ black box □ ________

Tester Information
| Name of Tester: | Jacob Louie | Date: | 11/11/2023
| HW/SW Version: | HW: Rev 4, SW: Final Version 2.0 | Time: | 5:00PM
| Setup: | When programming the chip, you need to make sure you erase the EEPROM so it has no calibration data saved.
Test Action | | Expected Result | Pass | Fail | N/A | Comments
1 | Power on the device for the first time after an EEROM wipe. | Will enter calibration mode, and it will say that it’s entering calibration mode on the OLED display. | ✅ | | | Works how it should
2 | Finish calibration | Should go to idle mode, OLED display will be blank. | ✅ | | | Works how it should
3 | After calibration, read some colors, power cycle the device, then read those same colors. | Will go straight to idle mode and display a “Hello :)”. The color sensor will show the same results as before it was power cycled. | ✅ | | | Works how it should
| Overall test result: | | ✅ | | | Does what’s expected.

Test Author: Jacob Louie
Test Case Name: | Test idle state in code | Test ID #: | 0006
Description: | Test that it should wait for button press while in idle mode and that debounce code works as it should. | Type: | ✓ white box □ black box □ ________

Tester Information
| Name of Tester: | Jacob Louie | Date: | 11/11/2023
| HW/SW Version: | HW: Rev 4, SW: Final Version 2.0 | Time: | 5:30PM
| Setup: | Program chip as usual. Calibrate the color sensor if not done already.
Test Action | | Expected Result | Pass | Fail | N/A | Comments
1 | Test debounce by increasing the debounce delay so it’s noticeable that a button press isn’t being registered. Press button for .5 seconds. | A very short button press should do nothing. Will stay in idle mode | ✅ | | | Works how it should
2 | Make debounce delay what it should be (50). Press button for .5 seconds. | Will go into color sensing mode. Will display a new color value. | ✅ | | | Works how it should
3 | Hold the button down for at least 10 seconds. | Will go into calibration mode. Will display “calibration…” | ✅ | | | Works how it should
| Overall test result: | | ✅ | | | Does what’s expected.

Test Author: Jacob Louie
Test Case Name: | Test color sensing state in code | Test ID #: | 0007
Description: | Verify that it’s getting new color values when it enters the color sensing state and that it goes to the idle state after it is done. | Type: | ✓ white box □ black box □ ________

Tester Information
| Name of Tester: | Jacob Louie | Date: | 11/11/2023
| HW/SW Version: | HW: Rev 4, SW: Final Version 2.0 | Time: | 6:00PM
| Setup: | Program chip as usual. Calibrate the color sensor if not done already.
Test Action | | Expected Result | Pass | Fail | N/A | Comments
1 | Press the button while trying to read the color red. Then Press the button again while trying to read the color blue. | The HEX value on the display should change, and it should show the blue HEX value on the display. | ✅ | | | Works how it should
| Overall test result: | | ✅ | | | Does what’s expected.

Test Author: Josue Tristan

Test Case Name: | Durability Test | Test ID #: | 0008
Description: | To test the durability, ease of disassembly, and reassembly of the housing. This test ranges from table drops to each member attempting to assemble. Test the integrity after assembly/disassembly and note down any wear | Type: | □ white box □ black box ✓ Other

Tester Information

| Name of Testers: | Josue Tristan | Date: | 11/30/23
| HW/SW Version: | Final Case Version 3.0 | Time: | 2:37PM
| Setup: | Involves a table drop from 30 inches with 2.5 lb weight on it
T E S T | ACTIONS: | TESTING FOR: | P A S S | F A I L | N / A | Actual results
1 | Dropped from 30in (waist high) | Small dent/crack | ✓ | | | No damage
2 | Reassemble the device | Any signs of wear and/or deform from the forces applied after assembling | ✓ | | | No signs of deform, still holds together
3 | Disassemble the device | Any signs of wear and/or deform from the forces applied after disassembling | ✓ | | | No signs of wear/deform
4 | Stress test: 2.5 lbs placed on top | Signs of wear and/or deform from heavy stress | ✓ | | | No signs of damage
| Overall test result: It passed the benchmarks we sent | | ✓ | | | Performed very well in those testings

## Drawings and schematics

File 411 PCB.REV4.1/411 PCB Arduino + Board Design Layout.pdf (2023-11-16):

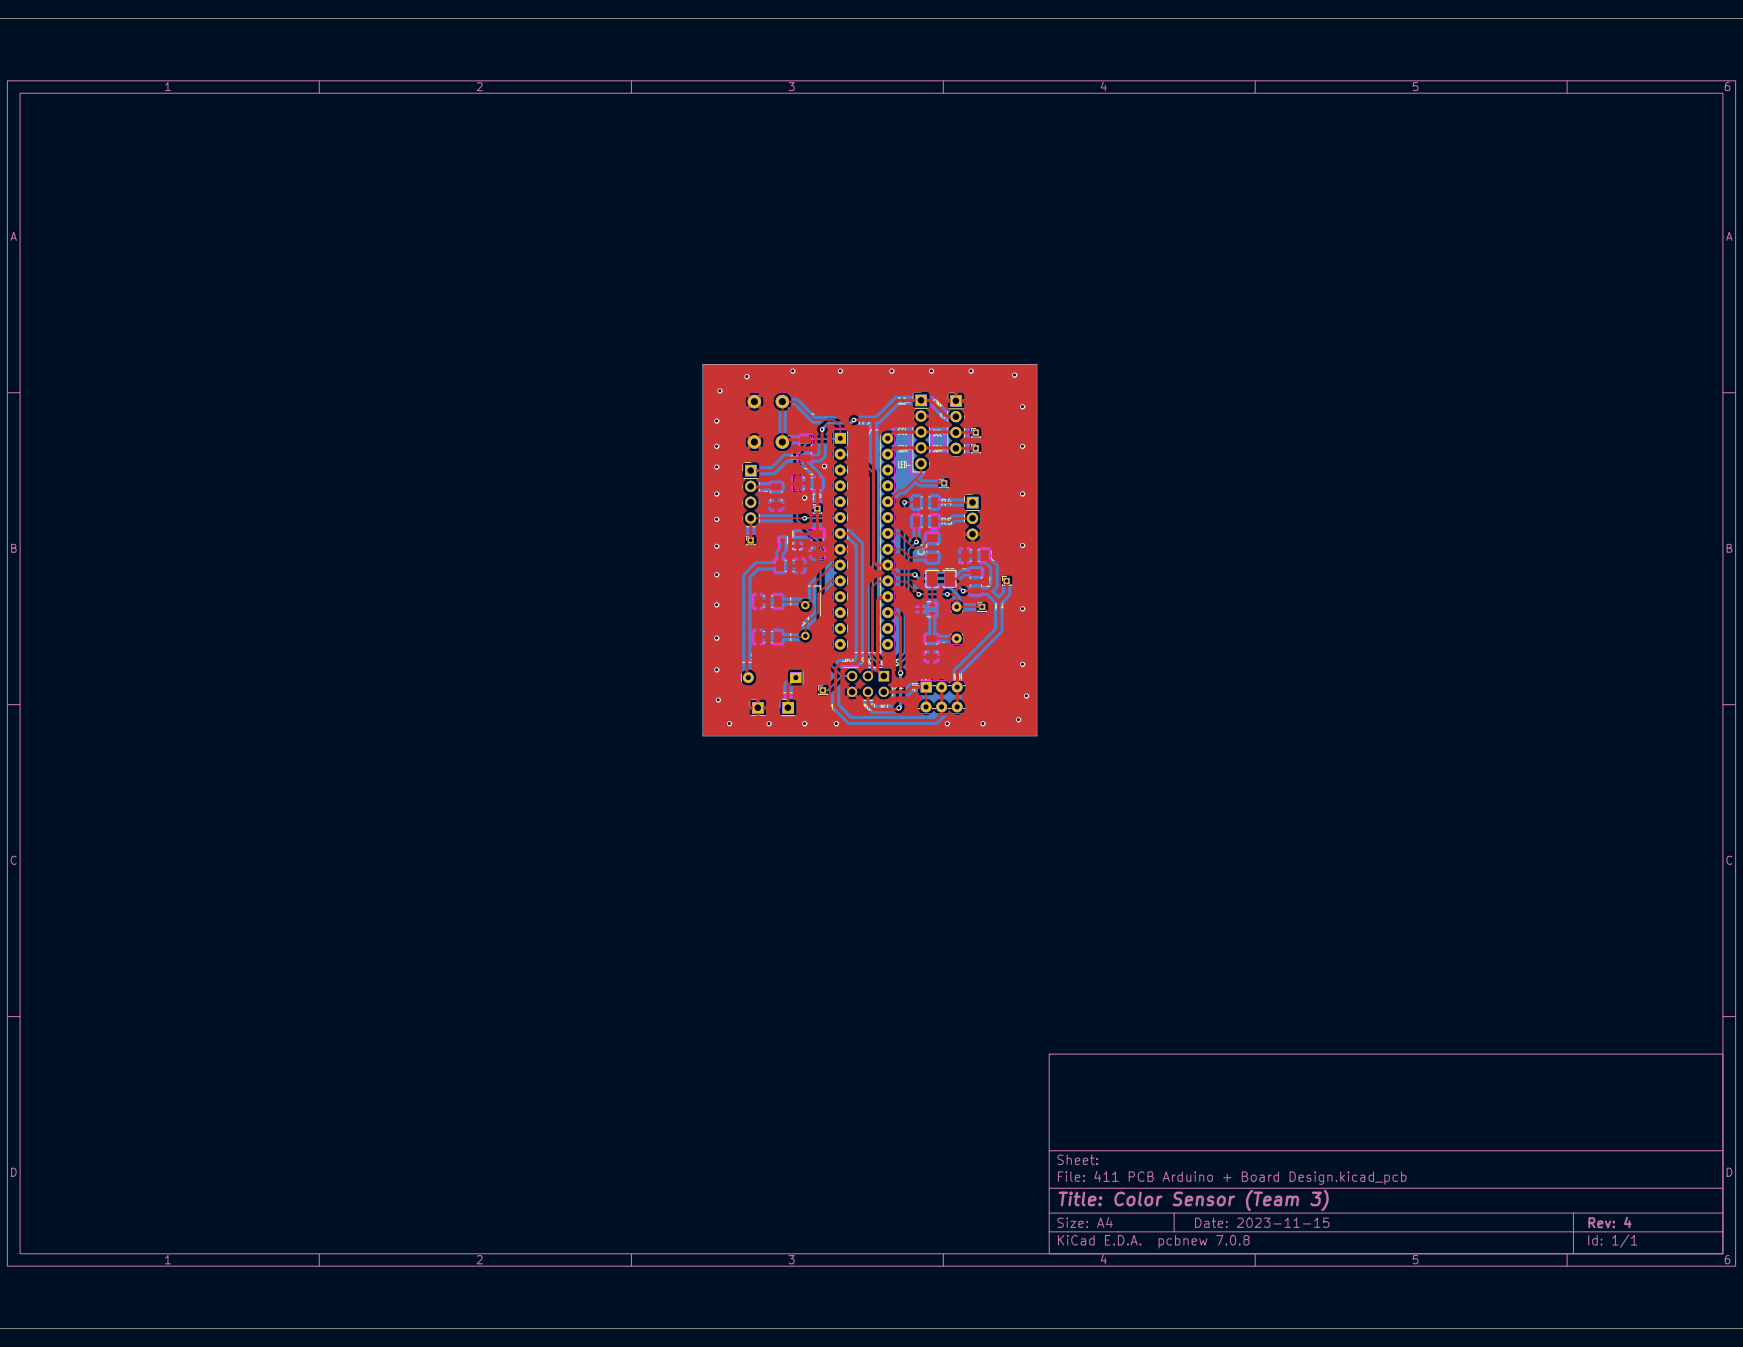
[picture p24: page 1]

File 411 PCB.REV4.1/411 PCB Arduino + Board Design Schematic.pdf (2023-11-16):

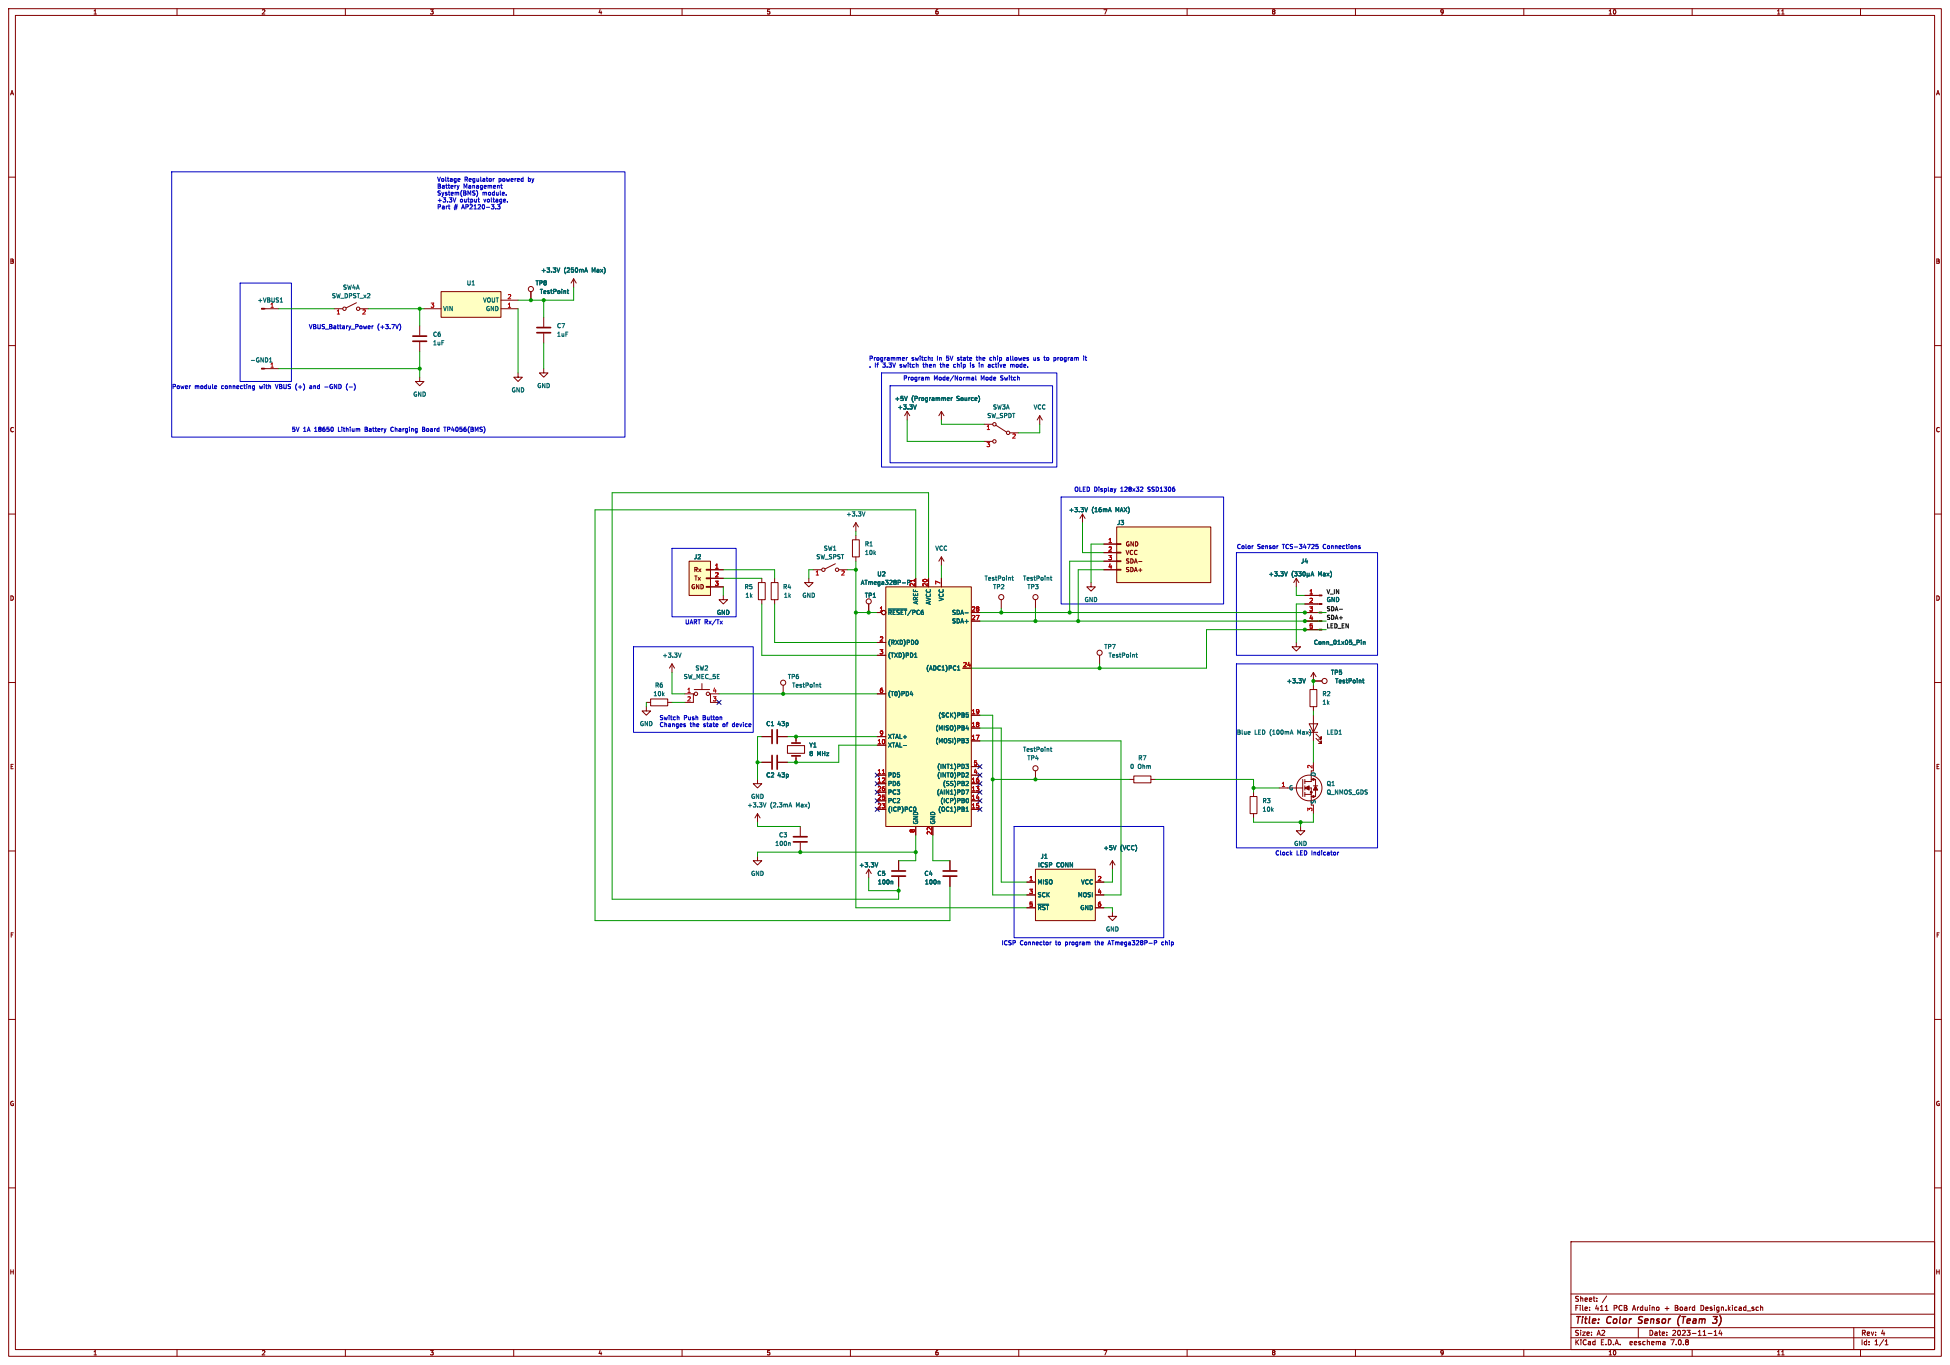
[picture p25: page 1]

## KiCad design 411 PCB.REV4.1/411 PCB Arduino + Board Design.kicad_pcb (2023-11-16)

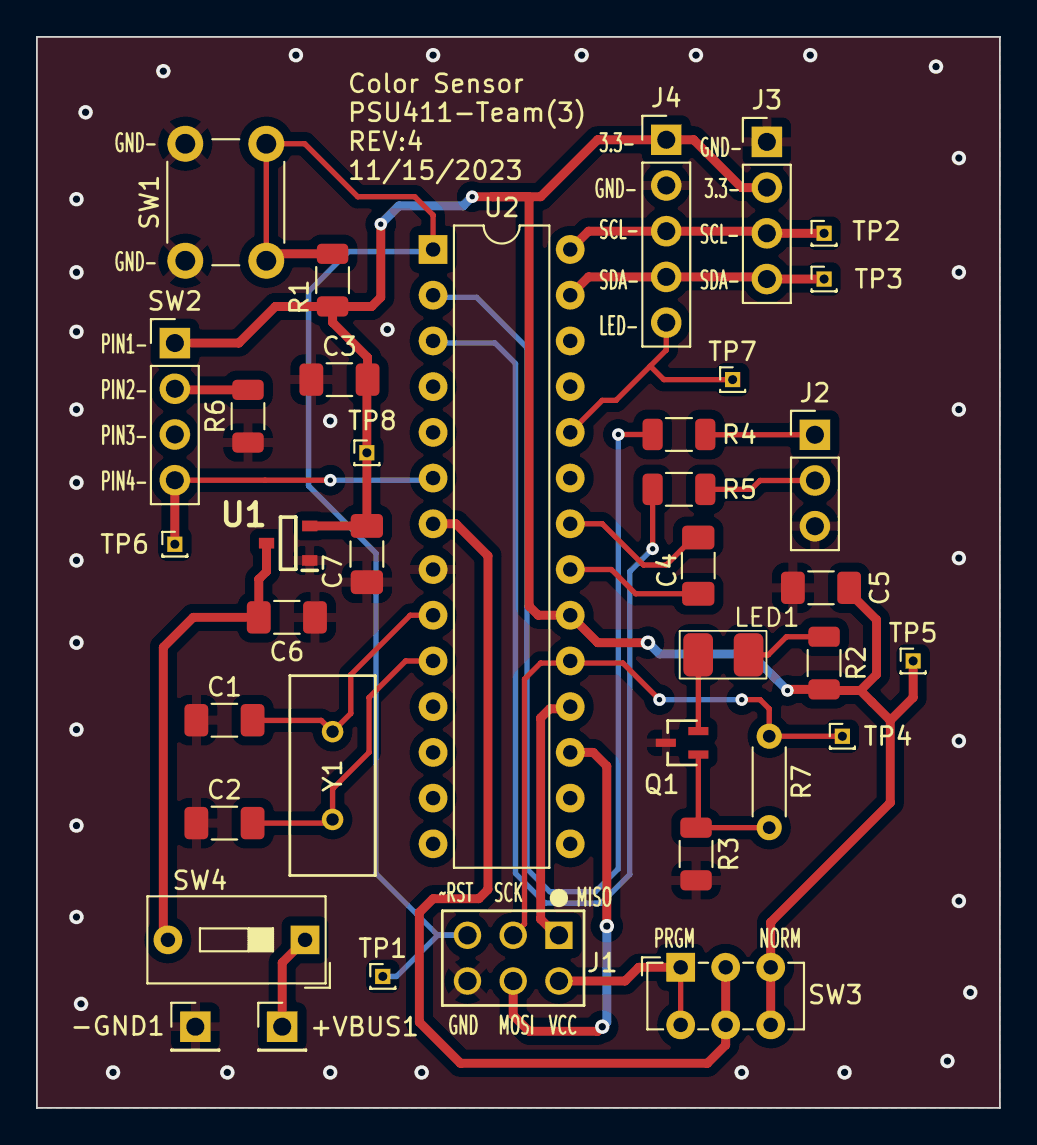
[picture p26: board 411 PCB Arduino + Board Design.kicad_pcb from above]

Board: 2 copper layers, 53.5 x 59.5 mm, 37 parts (0 on the bottom side), 26 nets.

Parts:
+VBUS1: Conn_01x01_Pin; PinHeader_1x01_P2.54mm_Vertical
-GND1: Conn_01x01_Pin; PinHeader_1x01_P2.54mm_Vertical
C1, C2: 30p; C_1206_3216Metric_Pad1.33x1.80mm_HandSolder
C3, C4, C5: 100n; C_1206_3216Metric_Pad1.33x1.80mm_HandSolder
C6, C7: 1uF; C_1206_3216Metric_Pad1.33x1.80mm_HandSolder
J1: ICSP CONN; CONN_PH2-06-UA_ADM
J2: PinHeader_1x03_P2.54mm_Vertical
J3: Conn_01x04; PinHeader_1x04_P2.54mm_Vertical
J4: Conn_01x05_Pin; PinHeader_1x05_P2.54mm_Vertical
LED1: Blue LED (100mA Max); LTST-B680
Q1: Q_NMOS_GDS; SOIC_D8LW-13_DIO
R1, R3, R6: 10k; R_1206_3216Metric
R2, R4, R5: 1k; R_1206_3216Metric
R7: 0 Ohm; R_Axial_DIN0204_L3.6mm_D1.6mm_P5.08mm_Horizontal
SW1: SW_SPST; SW_PUSH_6mm
SW2: SW_MEC_5E; PinHeader_1x04_P2.54mm_Vertical
SW3: SW_SPDT; SW_E-Switch_EG1271_SPDT_123
SW4: SW_DPST_x2; SW_DIP_SPSTx01_Slide_9.78x4.72mm_W7.62mm_P2.54mm
TP1, TP2, TP3, TP4, TP5, TP6, TP7, TP8: TestPoint; PinHeader_1x01_P1.00mm_Vertical
U1: SOT96P240X120-3N
U2: ATmega328P-P; DIP-28_W7.62mm
Y1: 8 MHz; ATS08A-E_CTS

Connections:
+3.3V: C3.2, C5.2, C7.1, J3.2, J4.1, R1.1, R2.1, SW2.1, SW3.3 (C), TP5.1, TP8.1, U1.2 (VOUT), U2.20 (AVCC)
+5V: J1.2 (VCC), SW3.1 (A)
/LED_EN: J4.5, TP7.1, U2.24 ((ADC1)PC1)
/SDA+: J3.4, J4.4, TP3.1, U2.27 (SDA+)
/SDA-: J3.3, J4.3, TP2.1, U2.28 (SDA-)
GND: -GND1.1, C1.1, C2.1, C3.1, C5.1, C6.2, C7.2, J1.6 (GND), J2.3, J3.1, J4.2, Q1.3 (S), R3.2, R6.1, SW1.1 (A), U1.1 (GND), U2.8 (GND)
unnamed: +VBUS1.1, SW4.1 (A)
unnamed: C4.2, U2.22 (GND)
unnamed: J1.1 (MISO), U2.18 ((MISO)PB4)
unnamed: J1.4 (MOSI), U2.17 ((MOSI)PB3)
unnamed: J1.3 (SCK), R7.2, TP4.1, U2.19 ((SCK)PB5)
unnamed: J1.5 (~RST), R1.2, SW1.2 (B), TP1.1, U2.1 (~RESET/PC6)
unnamed: J2.1, R4.2
unnamed: J2.2, R5.2
unnamed: LED1.2 (A), R2.2
unnamed: LED1.1 (K), Q1.2 (D)
unnamed: Q1.1 (G), R3.1, R7.1
unnamed: R6.2, SW2.2
unnamed: SW2.4 (A), TP6.1, U2.6 ((T0)PD4)
unnamed: C6.1, SW4.2 (B), U1.3 (VIN)
unnamed: R4.1, U2.2 ((RXD)PD0)
unnamed: R5.1, U2.3 ((TXD)PD1)
unnamed: C4.1, U2.21 (AREF)
unnamed: C1.2, U2.9 (XTAL+), Y1.2
unnamed: C2.2, U2.10 (XTAL-), Y1.1
VCC: SW3.2 (B), U2.7 (VCC)

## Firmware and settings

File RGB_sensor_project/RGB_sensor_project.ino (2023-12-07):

// I2C library
#include <Wire.h>
// OLED display library
#include <Adafruit_SSD1306.h>
// RGB color sensor library
#include <Adafruit_TCS34725.h>
// Non-volatile memory
#include <EEPROM.h>


// Turn on serial debug code
// 1 = debug on
// 0 = debug off
#define debug 0

// mode/state of operation
#define calibrationMode       1
#define colorSensingMode      2
#define idleMode              3
#define sleepMode             4

// Threshold time for button press
// decuces misclick
#define debounceDelay 50

// Button pin
#define buttonPin 4 //Pin 6 on Raw ATmega //Pin 4 on Arduino Uno //Pin 4 on Color Sensor PCB

#define minRedLocation    0
#define maxRedLocation    6
// Sensor LED pin
#define senpin  A1  //Pin 24 on Raw ATmega // A1 on Arduino Uno
// OLED Parameters
#define SCREEN_WIDTH    128 // OLED display width, in pixels
#define SCREEN_HEIGHT    32 // OLED display height, in pixels
#define OLED_RESET       -1 // Reset pin # (or -1 if sharing Arduino reset pin)
#define SCREEN_ADDRESS 0x3C // See datasheet for Address; 0x3D for 128x64, 0x3C for 128x32
Adafruit_SSD1306 display(SCREEN_WIDTH, SCREEN_HEIGHT, &Wire, OLED_RESET);

// RGB color sensor parameters
Adafruit_TCS34725 tcs = Adafruit_TCS34725(TCS34725_INTEGRATIONTIME_499MS, TCS34725_GAIN_4X); 

// state machine for mode of operation
/*  1 = color calibration mode  (hold button for x amount of time to enter calibration mode)
                                (after calibration, goes into idle mode)
    2 = color sensing mode      (after sensing color, goes into idle mode)
    3 = idle mode               (waiting for button press to enter color sensing mode) 
                                (if idle for x amount of time go into sleep mode)
    4 = sleep mode              (low power mode until button press, then go into color sensoing mode)
*/
//Initialize to calibration mode
uint8_t mode_state;

// Used to store button states and remove debounce
bool buttonReading;
bool lastButtonReading = LOW;
uint32_t startPress = 0;
uint32_t endPress = 0;

// Save these variables between loops (global)
// Calibration values
struct calibrationCodes{
  uint16_t min_red, min_green, min_blue;
  uint16_t max_red, max_green, max_blue; 
};
calibrationCodes cal_val;

void setup()
{
  // Set Baud rate
  if (debug == 1) Serial.begin(9600);

  // Initialize the pushbutton pin as an input:
  pinMode(buttonPin, INPUT);
  
  // Sensor LED as ounput to turn it off or on
  pinMode(senpin, OUTPUT);
  // Turn off RGB LED
  digitalWrite(senpin, LOW);

  // SSD1306_SWITCHCAPVCC = generate display voltage from 3.3V internally
  if(!display.begin(SSD1306_SWITCHCAPVCC, SCREEN_ADDRESS)) {
    if (debug == 1) Serial.println(("SSD1306 allocation failed"));
    while (1); // Don't proceed, loop forever
  }

  // Clear the buffer
  display.clearDisplay();
  
  // Initialize OLED display
  display.begin(SSD1306_SWITCHCAPVCC, SCREEN_ADDRESS);
  display.setTextSize(2);
  display.setTextColor(WHITE);
  display.setCursor(0,0);
  display.clearDisplay();
  display.display();

  if (tcs.begin()) {
    if (debug == 1) Serial.println("Color Sensor Working...");
  } else {
    if (debug == 1) Serial.println("No TCS34725 found ... check your connections");
    display.println("Color Sensor Error");
    display.display();
    while (1); // Don't proceed, loop forever
  }

  // IF first ever boot (EEPROM has no valid Data)
  if(( 0xFF == EEPROM.read(minRedLocation)) && (0xFF == EEPROM.read(maxRedLocation))){
    cal_val.min_red   = 255;
    cal_val.min_green = 255;
    cal_val.min_blue  = 255;
    cal_val.max_red   = 0;
    cal_val.max_green = 0;
    cal_val.max_blue  = 0;
    // Go to calibration mode
    mode_state = calibrationMode;
  }

  // Retrieve stored calibration values
  else{
    EEPROM.get(0, cal_val);
    // Go to idle mode
    mode_state = idleMode;
    display.clearDisplay();
    display.setCursor(0,0);
    display.println("Hello :)");
    display.display();
  }
  
}

void loop()
{
  // Raw RGB values
  uint16_t raw_red, raw_green, raw_blue, clear;
  // Real RGB values
  //was float
  int red, green, blue, total; 

  // Color calibration mode
  if(mode_state == calibrationMode){
    digitalWrite(senpin, HIGH);
    display.clearDisplay();
    display.setCursor(0, 0);
    display.println("\tCalibrating Mode...");
    display.display();
    delay(2000);

    // Tell user were entering black calibration
    display.display();
    display.clearDisplay();
    display.setCursor(0, 0);
    display.println("Calibrate for black");
    if (debug == 1) Serial.println("Calibrate for black");
    display.print("target: #000000");
    display.display();
    
    // Wait until button is pressed to collect black data
    while(digitalRead(buttonPin) == LOW){} 
  
    // Get all black RGB values
    tcs.getRawData(&raw_red, &raw_green, &raw_blue, &clear);
    cal_val.min_red   = raw_red; 
    cal_val.min_green = raw_green;
    cal_val.min_blue  = raw_blue;
    delay(500);

    // Tell user were entering white calibration
    display.clearDisplay();
    display.setCursor(0, 0);
    display.println("Calibrate for white");
    if (debug == 1) Serial.println("Calibrate for white");  //debug line
    display.print("target: #FFFFFF");
    display.display();
    delay(1000);

    // Wait unitl button is pressed to collect white data
    while(digitalRead(buttonPin) == LOW){}

    // Get all white RGB values
    tcs.getRawData(&raw_red, &raw_green, &raw_blue, &clear);
    cal_val.max_red   = raw_red; 
    cal_val.max_green = raw_green;
    cal_val.max_blue  = raw_blue;
    delay(1000);

    // Turn off LED on RBG sensor
    digitalWrite(senpin, LOW);

    // Save new calibration data to memory
    EEPROM.put(0,cal_val);

    // End calibration and go to idle state
    mode_state = idleMode;
    display.clearDisplay();
    // Let user know it's done with a message on the display
    display.setCursor(0, 0);
    display.println("Hello :)");
    display.display();
  }

  // Color sensing mode
  else if(mode_state == colorSensingMode){
    // Turn on light for Color Sensor
    digitalWrite(senpin, HIGH);
  
    display.clearDisplay();
    display.setCursor(0, 0);
    delay(1000);
    
    /*//Debug
    //////////////////////////////////////////////////////////// 
    Serial.print("Rmin: ");   Serial.print(min_red);
    Serial.print("\tGmin: "); Serial.print(min_green);
    Serial.print("\tBmin: "); Serial.print(min_blue);
    Serial.println();
    Serial.print("Rmax: ");   Serial.print(max_red);
    Serial.print("\tGmax: "); Serial.print(max_green);
    Serial.print("\tBmax: "); Serial.print(max_blue);
    Serial.println();
    //////////////////////////////////////////////////////////// 
    */

    // Sample Color sensor
    tcs.getRawData(&raw_red, &raw_green, &raw_blue, &clear);
    // Make adjustment based off of calibration
    // and conver raw value into RGB value
    red = constrain(map(raw_red, cal_val.min_red, cal_val.max_red, 0, 255),0,255);
    green = constrain(map(raw_green, cal_val.min_green, cal_val.max_green, 0, 255),0,255);
    blue = constrain(map(raw_blue, cal_val.min_blue, cal_val.max_blue, 0, 255),0,255);

    /*// Print RGB values to OLED Diplay
    display.print("R:");    display.print(int(red));   
    display.print(" G:");   display.println(int(green)); 
    display.print("B:");    display.print(int(blue));   
    */
    
    // Print Hex value to OLED Display
    display.print("Hex:"); 
    if(red < 16){display.print("0");}    //add leading zero
    display.print(int(red),HEX);
    if(green < 16){display.print("0");}  //add leading zero
    display.print(int(green),HEX);
    if(blue < 16){display.print("0");}  //add leading zero
    display.print(int(blue),HEX);
    display.display();
    
    /*// Debug
    Serial.print("R:");     Serial.print(int(red)); 
    Serial.print("\tG:");   Serial.print(int(green)); 
    Serial.print("\tB:");   Serial.print(int(blue));
    Serial.print("\n");
    */
    // Turn off LED on RBG sensor
    delay(1000);
    digitalWrite(senpin, LOW);

    // return to idle mode
    mode_state = idleMode;
  }
  
  // Idle mode
  else if(mode_state == idleMode){
    // Check if button has been pressed
    buttonReading = digitalRead(buttonPin);
    
    // Get time when button changes states
    if(buttonReading != lastButtonReading){
      //detect Rising edge of button press
      if(buttonReading == HIGH){
        startPress = millis();
        endPress = millis();
      }
      if(buttonReading == LOW){
        endPress = millis();
      }
    }
    // Rcognise button press if button was held down longer than debounceDelay 
    if((endPress - startPress) > debounceDelay){
      if((endPress - startPress) > 4500){
        mode_state = calibrationMode;
        // Debug
        if (debug == 1) Serial.println("go to colorSensingMode");
      }
      else{
        mode_state = colorSensingMode;
        // Debug
        if (debug == 1) Serial.println("go to calibrationMode");
      }
      // Reset button timmer
      startPress = 0;
      endPress = 0;
    }
    lastButtonReading = buttonReading;
  }

  //state = 4 (sleep mode)
  else{
  }
  
}

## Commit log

2023-10-28 Create RGB_sensor_project.ino (#1)
    Arduino projector, getting basics of the color sensor and display working (together).
2023-11-06 Updated Folder Layout
    Newest PCB update
    [411 PCB Arduino + Board Design.csv, 411 PCB Arduino + Board Design.kicad_pcb, 411 PCB Arduino + Board Design.kicad_sch]
2023-11-06 Latest Schematic and PCB footprints
    Update-
    [411 PCB Arduino + Board Design.kicad_pcb, 411 PCB Arduino + Board Design.kicad_sch]
2023-11-08 Adding first version of Bill Of Materials.
    [Bill of Materials.xlsx]
2023-11-08 Updated PCB Layout
    [411 PCB Arduino + Board Design.kicad_pcb, 411 PCB Arduino + Board Design.kicad_sch]
2023-11-08 Updated bill of materials
    [Bill of Materials.xlsx]
2023-11-08 Update Bill of Materials.xlsx
    [Bill of Materials.xlsx]
2023-11-09 added lide switch
    [Bill of Materials.xlsx]
2023-11-09 Updated values and descriptions on Schematic
    Changed the capacitor values for the 8MHz clock from 20pF to 10pF. Added the Max current consumption of the color sensor, display, LED, and ATmega328P-PN. Also added the Max Current output for the Vo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
    [411 PCB Arduino + Board Design.kicad_sch]
2023-11-10 New rev
    [411 PCB Arduino + Board Design.csv, 411 PCB Arduino + Board Design.kicad_pcb, 411 PCB Arduino + Board Design.kicad_sch]
2023-11-10 New Schematic for Rev 3 and updated BOM
    [411 PCB Arduino + Board Design.kicad_sch, Bill of Materials.xlsx]
2023-11-12 EEPROM, Debounce, more testpoints (#2)
    * Create RGB_sensor_project.ino
    * Removed RGB LED code and cleaned up code
    * added LED connection for RGB Sensor
    * starting to incorporate EEPROM
    * Added EEPROM code and changed the pins for button and RGB Sensors LED. Also changed how the chip goes into calibration mode
    * pins that work
    * Fixed debounce error and added more test points to schematic
    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
    [411 PCB Arduino + Board Design.kicad_sch]
2023-11-13 Rev4 Fixed Footprint and Schematic Layout a bit.
    Monday 11/13/2023 Will do the PCB final routing
    [411 PCB Arduino + Board Design.kicad_pcb, 411 PCB Arduino + Board Design.kicad_sch, Bill of Materials.xlsx]
2023-11-13 411 PCB Rev4+ Updated and Routed Layout
    This is the pre submission board. Before Ben check
    [411 PCB Arduino + Board Design.kicad_pcb, 411 PCB Arduino + Board Design.kicad_sch]
2023-11-14 OSH Park example
    [411 PCB Arduino + Board Design-B_Cu.gbr, 411 PCB Arduino + Board Design-B_Mask.gbr, 411 PCB Arduino + Board Design-B_Paste.gbr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]
2023-11-15 PCB Layout REV 4
    Updated Schematic and Layout (Added power switches, fixed Atmega pin out schematic, changed pin outputs on color sensor, added 3.3V to 5V throw select switch)
    [411 PCB Arduino + Board Design.kicad_pcb, 411 PCB Arduino + Board Design.kicad_sch]
2023-11-15 updated capacitators for crystal to 40pF
    [411 PCB Arduino + Board Design.kicad_sch]
2023-11-15 43pF caps were the closest values of Digikey
    [411 PCB Arduino + Board Design.kicad_sch]
2023-11-15 update BOM and real capacitor value for crystal
    [Bill of Materials.xlsx]
2023-11-16 pdf for pcb
2023-11-16 Updated Board + PCB purchase receipt
    Yes
    [411 PCB Arduino + Board Design.kicad_pcb, 411 PCB Arduino + Board Design.kicad_sch]
2023-11-16 Updated PCB and Loaded Receipt Board Purchase
2023-11-16 Uploaded Final Schematic and Layout PDF
2023-11-16 Final Updates during purchase
    [411 PCB Arduino + Board Design.csv]
2023-11-28 Hello :) on turn on
    I added a Hello message when you turn on the device so you know it's working. Also fixed color sensor not detected error displaying correctly on OLED display. OLED display shouldn't say if it is working (only in debug uart).
    [RGB_sensor_project.ino]
2023-11-29 Fixed AVCC and Big Button pinout on schamatic
    The AVCC should be connected to VCC and not 3.3V because when it's powered by 5V the AVCC pin would output 5V towards the Voltage regulator. The SW2 (big button) had ground on the wrong pin (floating input). It's now corrected so that it properly acts as an active high button.
    [411 PCB Arduino + Board Design.csv, 411 PCB Arduino + Board Design.kicad_pcb, 411 PCB Arduino + Board Design.kicad_sch]
2023-11-29 removed extra connection to 3.3V for no reason on AVCC line
    [411 PCB Arduino + Board Design.kicad_sch]
2023-11-29 Removed C3 from BOM (Rev 4.1)
    [Bill of Materials (Rev 4.1).xlsx]
2023-12-04 Pics of Version 2.5
    updated lens with cap
2023-12-06 Add hello message after finishing calibration
2023-12-07 Fixed display bug. Forgot to add "setCursor"."
    [RGB_sensor_project.ino]
2023-12-07 Added switch/flag for serial debug code
2023-12-07 Increase the amount of time the light is on. This fixes the variance between measurements of the same color.
    [RGB_sensor_project.ino]
